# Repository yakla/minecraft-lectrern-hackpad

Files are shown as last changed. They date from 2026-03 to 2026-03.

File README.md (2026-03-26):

# Minecraft Lectern Hackpad
A custom 6-key mechanical macro pad inspired by the Minecraft Lectern, designed for the **Hack Club Blueprint**.

## The Vision
the idea was i fast hackpad project with cool visuals. so i made it with a minecraft lectern block.
## Technical Specs
* **Controller:** Seeed Studio XIAO RP2040
* **Keys:** 6 Mechanical Switches (3x2 Matrix)
* **Visuals:** 128x32 OLED Display + WS2812B RGB LEDs
* **Firmware:** KMK / CircuitPython

# Hardware
* **XIAO RP2040** – The microController
* **6 x Mechanical Switches** - hackpad keys
* **1 x 0.91" White OLED** – Crisp 128x32 display for real-time status and custom graphics.
* **4 x WS2812B RGB LEDs** – Integrated lighting for that essential setup flex.
* **Custom 2-Layer PCB** – Engineered in KiCad 
* **6 x 1N4148W Diodes**

## Design Process
- **CAD:** Designed in **Onshape**. https://cad.onshape.com/documents/4aa1c7f92bdb34f3150a863a/w/03df906dbdf565c718d04fe4/e/68b5d359d9c8e5f142904c5d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
- **PCB:** Custom 2-layer board designed in **KiCad** with SMD diode protection.            |

## cad


## pcb design



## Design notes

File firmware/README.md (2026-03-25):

# KMK Firmware Setup

This repo already includes a local copy of KMK in [`../kmk_firmware`](../kmk_firmware).

## Board mapping

These pins were taken from the KiCad PCB for the XIAO RP2040:

- Matrix columns: `D0`, `D1`, `D9`
- Matrix rows: `D2`, `D3`
- OLED: `D4` = SDA, `D5` = SCL
- WS2812 chain: `D10`

## What to copy to `CIRCUITPY`

1. Install CircuitPython for the Seeed Studio XIAO RP2040.
2. Copy `kmk_firmware/kmk/` to the root of `CIRCUITPY`.
3. Copy `kmk_firmware/boot.py` to the root of `CIRCUITPY`.
4. Copy [`main.py`](./main.py) and [`kb.py`](./kb.py) to the root of
   `CIRCUITPY`.
5. Copy these CircuitPython display libraries into `CIRCUITPY/lib/`:

   - `adafruit_displayio_ssd1306.mpy`
   - `adafruit_display_text/`
6. Copy this CircuitPython RGB library into `CIRCUITPY/lib/`:

   - `neopixel.py`

[`main.py`](./main.py) keeps the keymap minimal, but it does initialize the
OLED on `D4`/`D5` and the WS2812 LEDs on `D10`. The OLED defaults to an idle
screen and switches to the pressed key name for one second whenever a key is
pressed.

## Example Linux copy command

```sh
cp -r kmk_firmware/kmk /run/media/$USER/CIRCUITPY/
cp kmk_firmware/boot.py firmware/main.py firmware/kb.py /run/media/$USER/CIRCUITPY/
```

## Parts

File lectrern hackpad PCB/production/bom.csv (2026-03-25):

Designator | Footprint | Quantity | Value | LCSC Part #
D1, D2, D3, D4, D5, D6 | 1206 | 6 | D
D10, D7, D8, D9 | LED_WS2812B_PLCC4_5.0x5.0mm_P3.2mm | 4 | WS2812B
J1 | PinHeader_1x04_P2.54mm_Vertical | 1 | oled connectors
SW1, SW2, SW3, SW4, SW5, SW6 | MX-Solderable-1U | 6 | SW_Push
U1 | XIAO-Generic-Hybrid-14P-2.54-21X17.8MM | 1 | MOUDLE-SEEEDUINO-XIAO

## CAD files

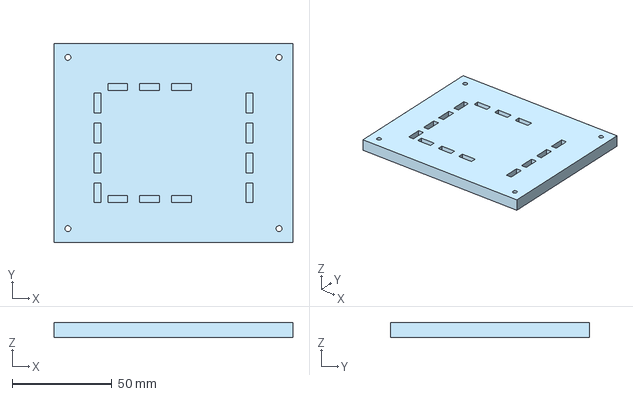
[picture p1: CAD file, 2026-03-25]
cad/lectrern hackpad.step
120.0 x 100.0 x 7.40 mm

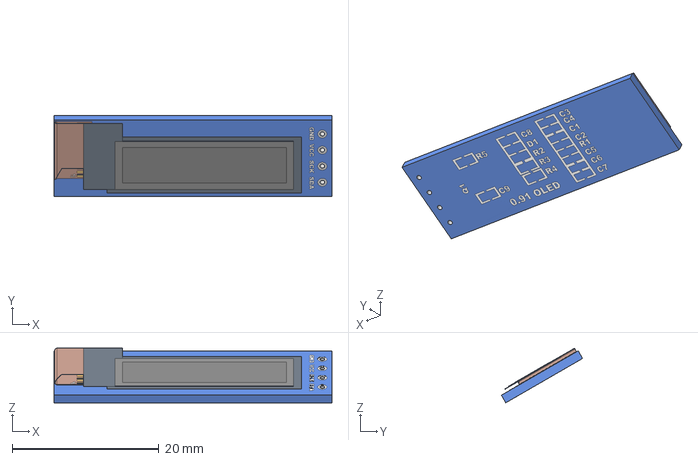
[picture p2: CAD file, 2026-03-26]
cad/parts/fast model - 0.91in oled Module - Board.step
37.9 x 11.1 x 7.45 mm

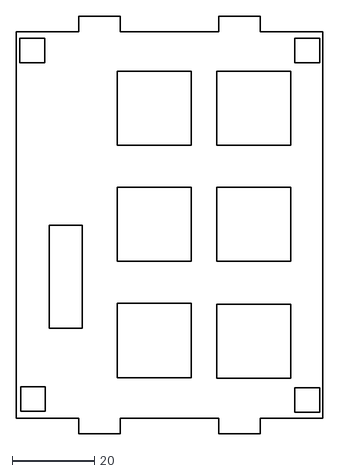
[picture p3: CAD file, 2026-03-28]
laser dxf files/fast model - top enclosure.dxf
74.4 x 101.4

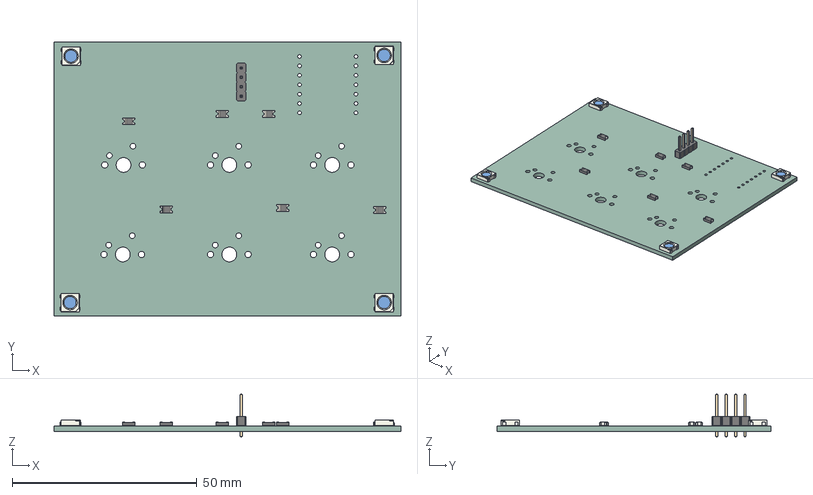
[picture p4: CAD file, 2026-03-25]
lectrern hackpad PCB/lectrern hackpad.step
93.8 x 74.0 x 11.5 mm
D_1206_3216Metric x 6
LED_WS2812B_PLCC4_5.0x5.0mm_P3.2mm x 4
PinHeader_1x04_P2.54mm_Vertical
lectrern hackpad_PCB

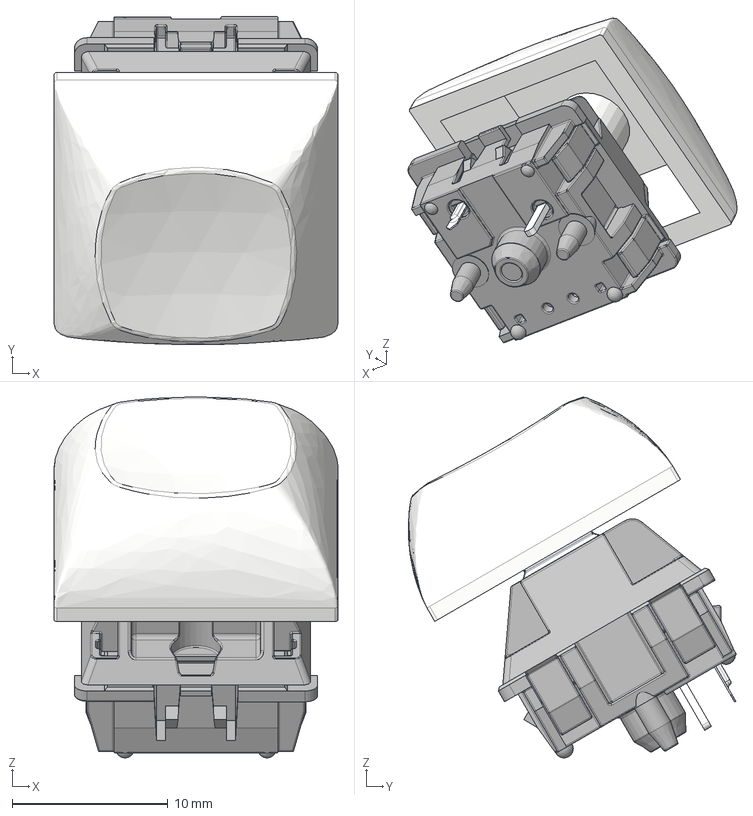
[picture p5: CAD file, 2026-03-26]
cad/parts/key.step
18.2 x 21.0 x 23.1 mm
MX �� ������_��_ __��1
���___Ĭ��__��_ x 2
MX�� ���� �ײ� �̡�2 __Ĭ��_��2____��_
MX �� ���娢��_���顧_ _
DSA 1u v2

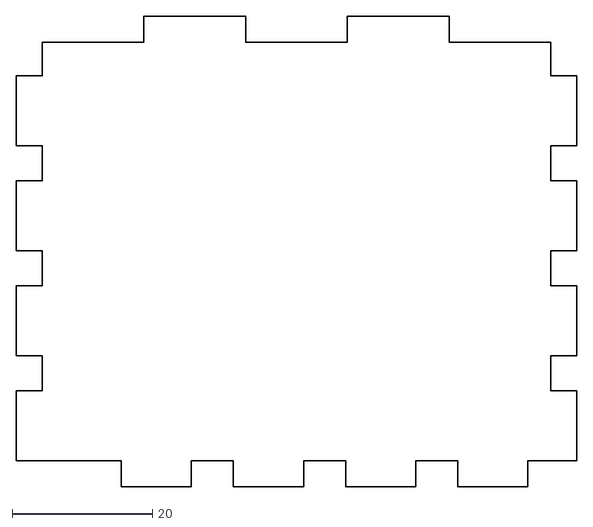
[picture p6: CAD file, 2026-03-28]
laser dxf files/fast model - back pannel.dxf
80.0 x 67.1

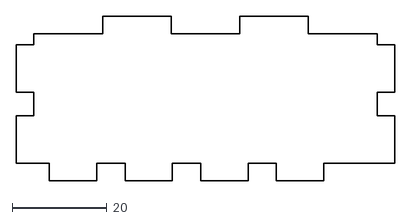
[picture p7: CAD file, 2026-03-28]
laser dxf files/fast model - front pannel.dxf
80.0 x 34.7

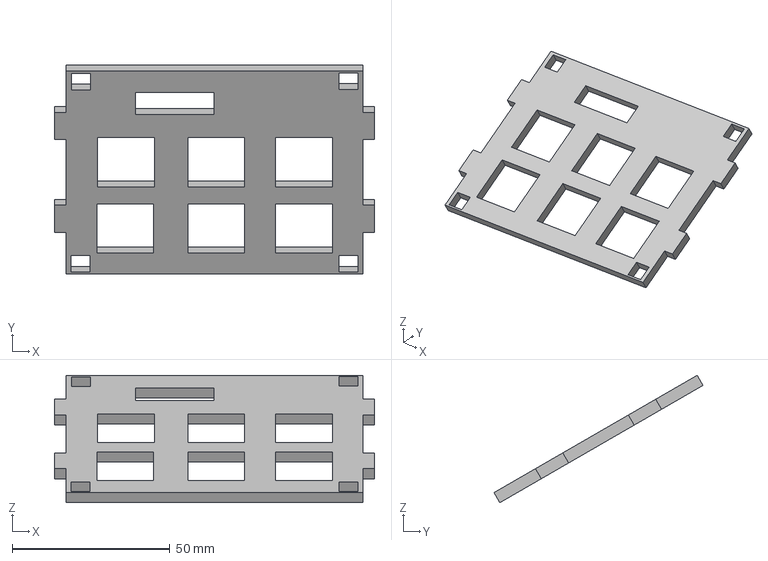
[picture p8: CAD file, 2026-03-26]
cad/parts/fast model - top enclosure.step
101.4 x 66.3 x 40.4 mm

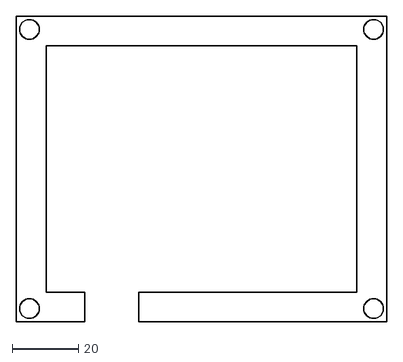
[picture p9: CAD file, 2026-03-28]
laser dxf files/fast model - top plate mid.dxf
112.0 x 92.4

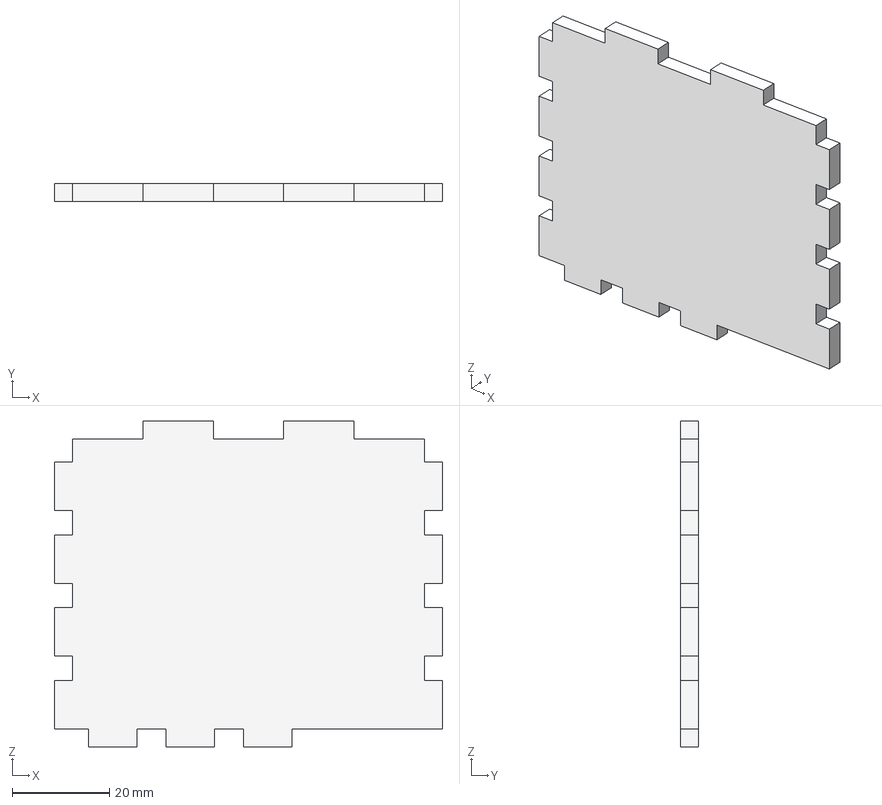
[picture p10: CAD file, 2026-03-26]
cad/parts/fast model - back pannel.step
80.0 x 3.70 x 67.1 mm

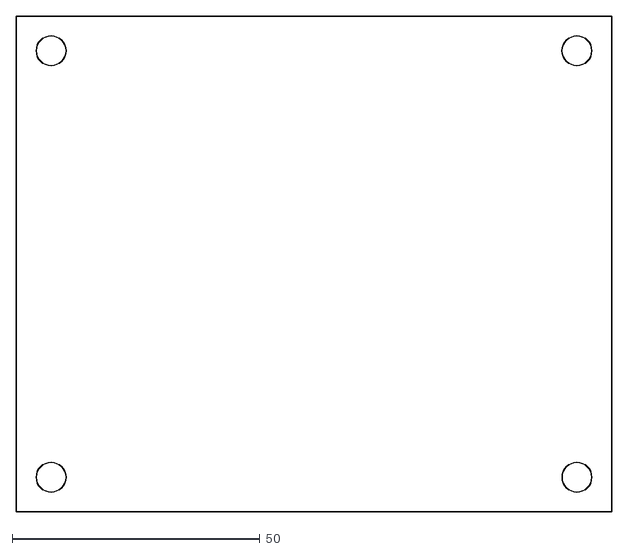
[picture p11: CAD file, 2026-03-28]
laser dxf files/fast model - base bottom.dxf
120.0 x 100.0

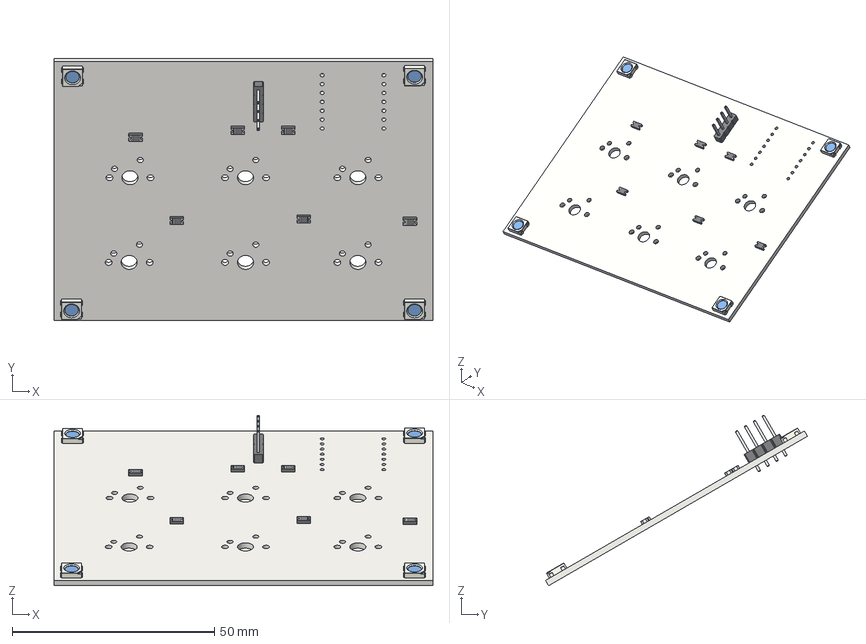
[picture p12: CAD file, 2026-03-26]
cad/parts/fast model - PCB.step
93.8 x 64.8 x 42.2 mm

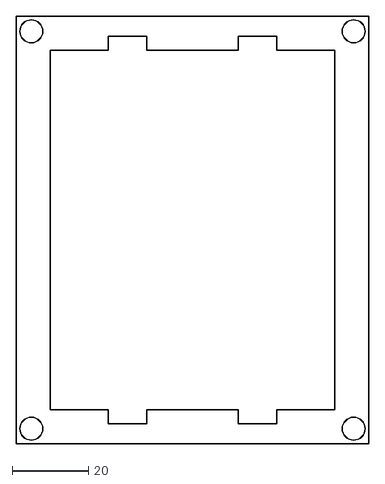
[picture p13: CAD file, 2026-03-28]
laser dxf files/fast model - top plate top.dxf
92.4 x 112.0

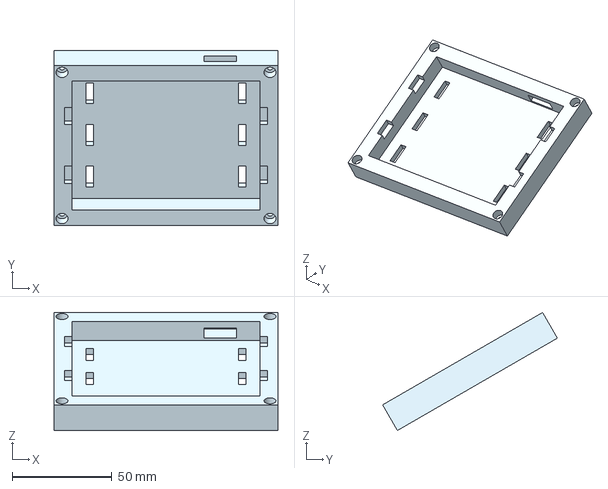
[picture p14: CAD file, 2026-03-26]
cad/parts/fast model - top plate.step
112.0 x 87.4 x 59.0 mm

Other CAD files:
cad/parts/fast model - base.step
laser dxf files/fast model - top plate bottom.dxf
cad/parts/fast model - left side pannel.step
laser dxf files/fast model - base top.dxf
cad/parts/fast model - front pannel.step
cad/parts/fast model - right side pannel.step

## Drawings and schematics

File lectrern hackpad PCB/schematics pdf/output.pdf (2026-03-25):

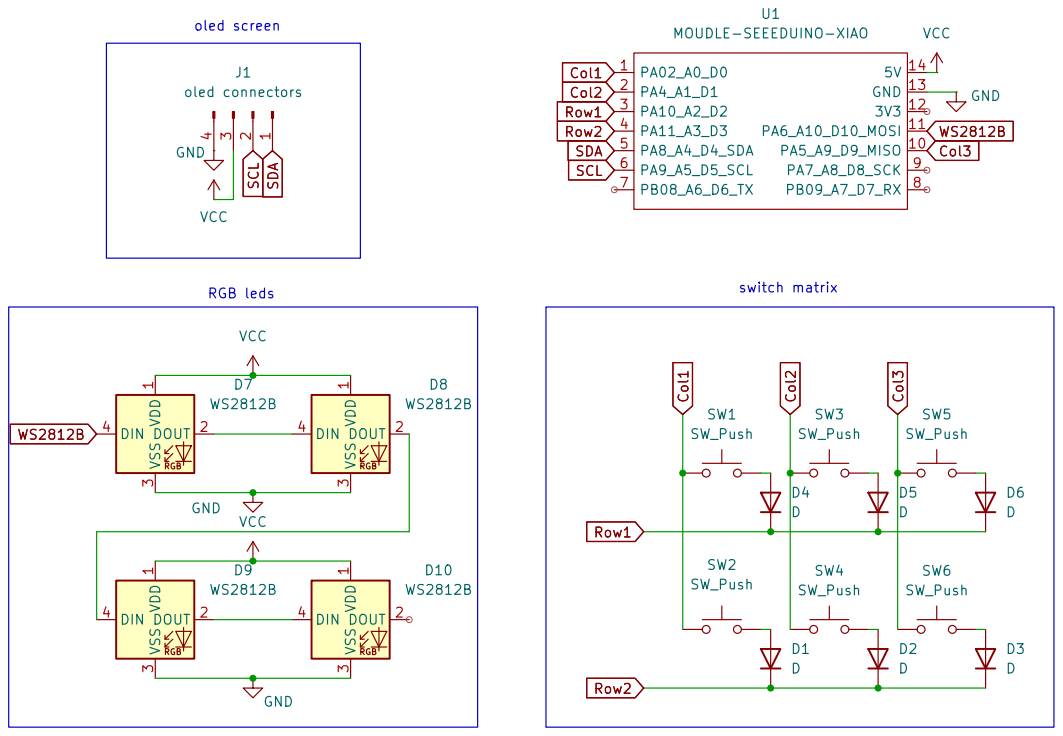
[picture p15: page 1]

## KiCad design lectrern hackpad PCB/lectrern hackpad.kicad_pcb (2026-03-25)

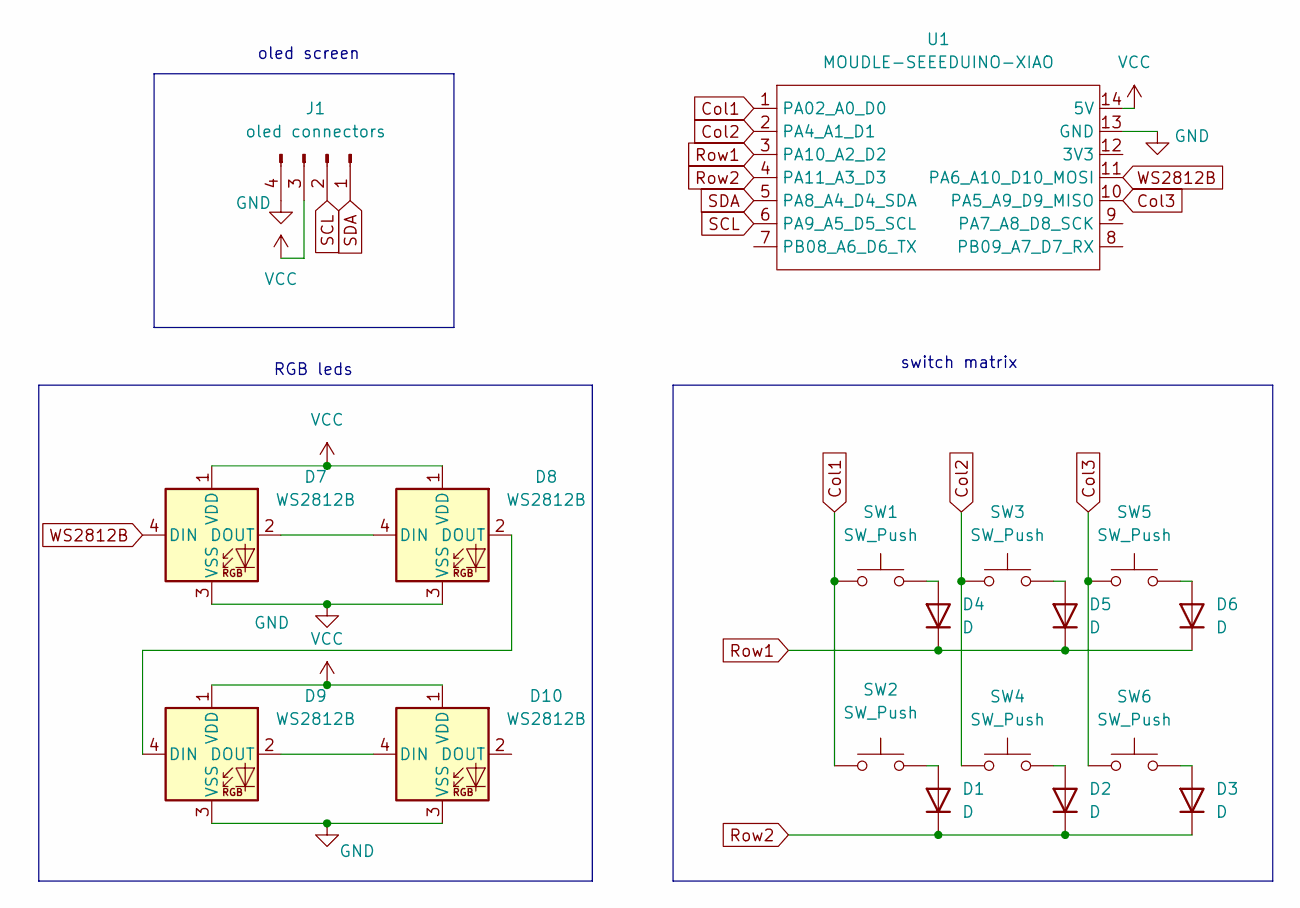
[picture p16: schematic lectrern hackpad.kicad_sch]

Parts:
D1, D2, D3, D4, D5, D6: D; D_1206_3216Metric_Pad1.42x1.75mm_HandSolder
D7, D8, D9, D10: WS2812B; LED_WS2812B_PLCC4_5.0x5.0mm_P3.2mm
J1: oled connectors; PinHeader_1x04_P2.54mm_Vertical
SW1, SW2, SW3, SW4, SW5, SW6: SW_Push; MX-Solderable-1U
U1: MOUDLE-SEEEDUINO-XIAO; XIAO-Generic-Hybrid-14P-2.54-21X17.8MM

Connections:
Col1: SW1.1, SW2.1, U1.1 (PA02_A0_D0)
Col2: SW3.1, SW4.1, U1.2 (PA4_A1_D1)
Col3: SW5.1, SW6.1, U1.10 (PA5_A9_D9_MISO)
GND: D7.3 (VSS), D8.3 (VSS), D9.3 (VSS), D10.3 (VSS), J1.4, U1.13 (GND)
unnamed: D1.2 (A), SW2.2
unnamed: D2.2 (A), SW4.2
unnamed: D3.2 (A), SW6.2
unnamed: D4.2 (A), SW1.2
unnamed: D5.2 (A), SW3.2
unnamed: D6.2 (A), SW5.2
unnamed: D7.2 (DOUT), D8.4 (DIN)
unnamed: D8.2 (DOUT), D9.4 (DIN)
unnamed: D9.2 (DOUT), D10.4 (DIN)
Row1: D4.1 (K), D5.1 (K), D6.1 (K), U1.3 (PA10_A2_D2)
Row2: D1.1 (K), D2.1 (K), D3.1 (K), U1.4 (PA11_A3_D3)
SCL: J1.2, U1.6 (PA9_A5_D5_SCL)
SDA: J1.1, U1.5 (PA8_A4_D4_SDA)
VCC: D7.1 (VDD), D8.1 (VDD), D9.1 (VDD), D10.1 (VDD), J1.3, U1.14 (5V)
WS2812B: D7.4 (DIN), U1.11 (PA6_A10_D10_MOSI)

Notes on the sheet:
RGB leds
switch matrix
oled screen

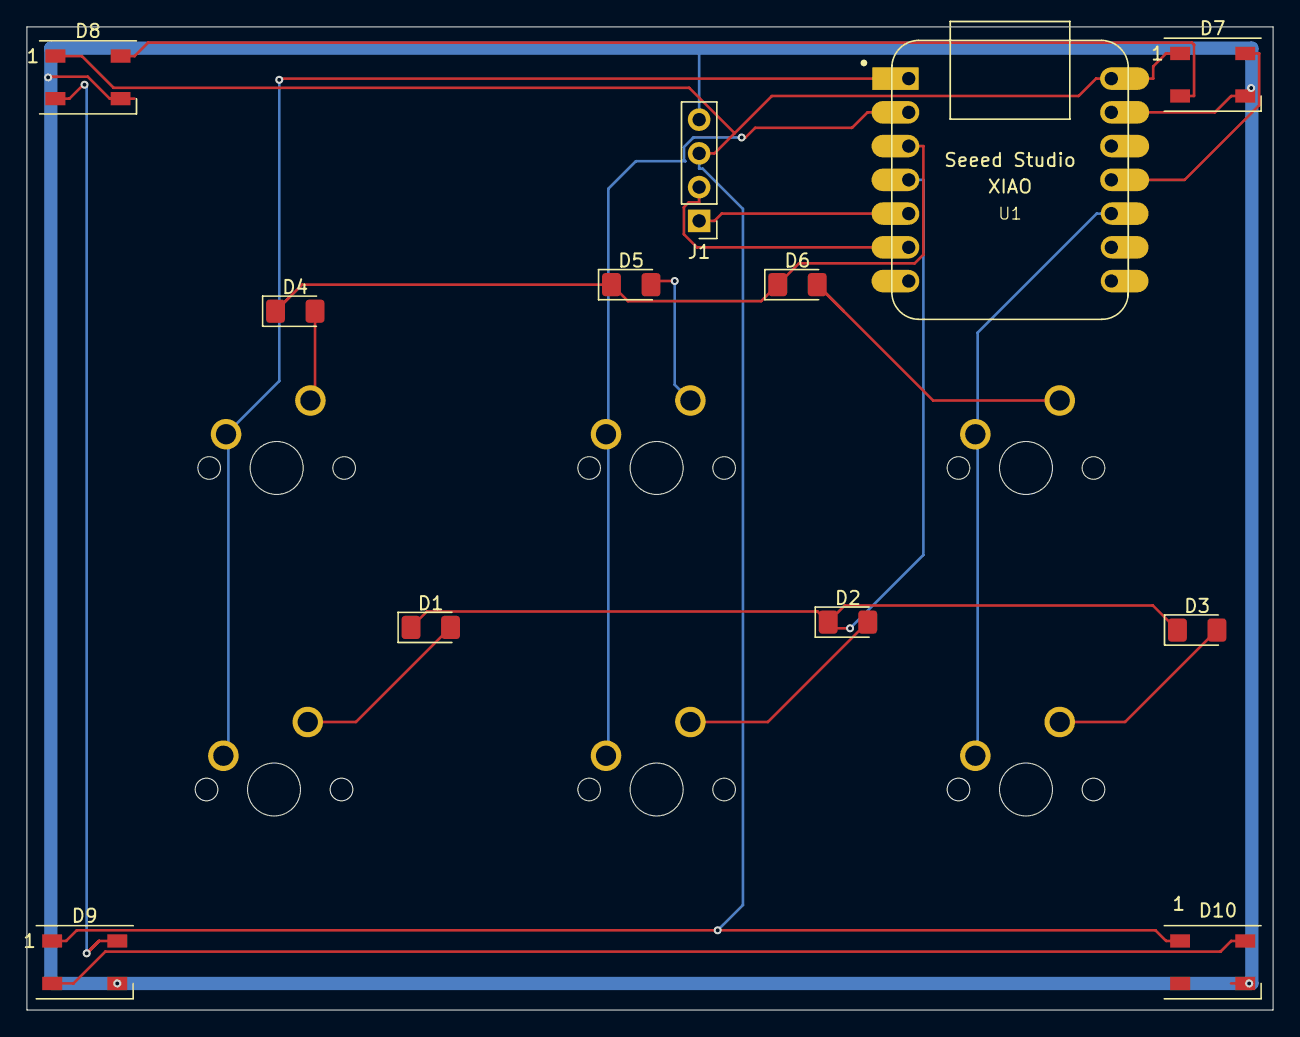
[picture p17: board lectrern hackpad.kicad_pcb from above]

Board: 2 copper layers, 93.8 x 74.0 mm, 18 parts (0 on the bottom side), 19 nets.

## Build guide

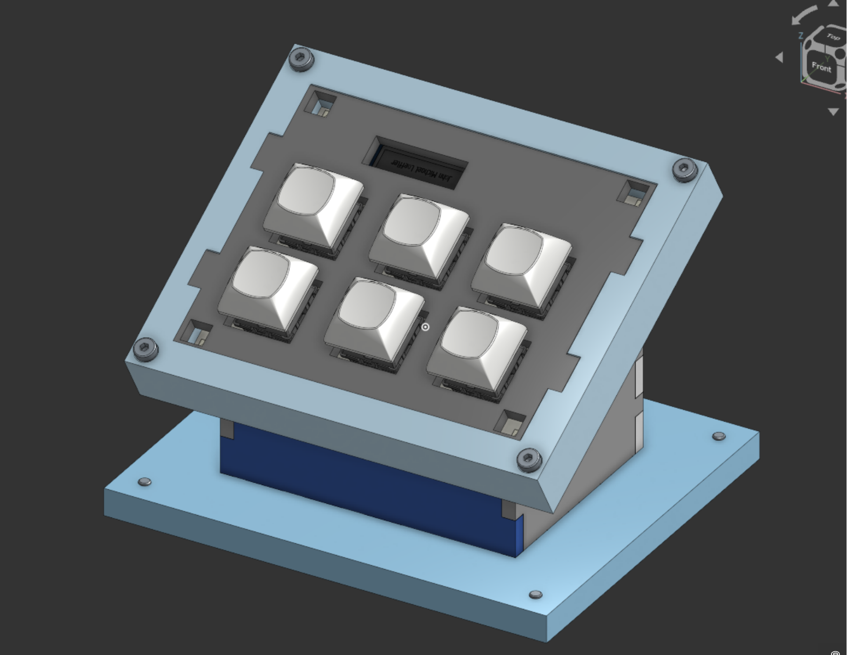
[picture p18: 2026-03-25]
Screenshot 2026-03-25 at 20-05-16 lectrern hackpad Assembly 1.png

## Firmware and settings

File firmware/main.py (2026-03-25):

from sys import path

import board

from kb import KMKKeyboard
from kmk.extensions.display import Display, TextEntry, ImageEntry
from kmk.extensions.display.ssd1306 import SSD1306
from kmk.extensions.rgb import RGB
from kmk.keys import KC
from kmk.modules import Module

keyboard = KMKKeyboard()

rgb = RGB(
    pixel_pin=board.D10,
    num_pixels=4,
    val_default=40,
)
keyboard.extensions.append(rgb)

display = Display(
    display=SSD1306(sda=board.D4, scl=board.D5),
    entries=[

        TextEntry(text='Minecraft', x=64, y=4, x_anchor='M', y_anchor='T'),
        TextEntry(text='Lectern', x=64, y=18, x_anchor='M', y_anchor='T'),
    ],
    flip=True,
)
keyboard.extensions.append(display)

KEY_LABELS = {
    0: 'F13',
    1: 'F14',
    2: 'F15',
    3: 'F16',
    4: 'F17',
    5: 'F18',
}


def show_idle():
    display.entries = [
        ImageEntry(image = "key_up.bmp", x=32, y=16),
        TextEntry(text='Minecraft', x=96, y=16, x_anchor='M', y_anchor='T'),
    ]
    display.render(keyboard.active_layers[0])


def show_pressed(name):
    display.entries = [
        ImageEntry(image = "key_down.bmp", x=32, y=16),
        TextEntry(text=name, x=100, y=16, x_anchor='M', y_anchor='T'),
    ]
    display.render(keyboard.active_layers[0])


class DisplayListener(Module):
    def __init__(self):
        self._timeout = None

    def during_bootup(self, keyboard):
        return

    def before_matrix_scan(self, keyboard):
        return

    def after_matrix_scan(self, keyboard):
        return

    def process_key(self, keyboard, key, is_pressed, int_coord):
        if is_pressed and int_coord is not None:
            show_pressed(KEY_LABELS.get(int_coord, f'Key {int_coord + 1}'))

            if self._timeout is not None:
                keyboard.cancel_timeout(self._timeout)

            self._timeout = keyboard.set_timeout(1000, show_idle)

        return key

    def before_hid_send(self, keyboard):
        return

    def after_hid_send(self, keyboard):
        return

    def on_powersave_enable(self, keyboard):
        return

    def on_powersave_disable(self, keyboard):
        return


keyboard.modules.append(DisplayListener())

keyboard.keymap = [
    [
        KC.F13,
        KC.F14,
        KC.F15,
        KC.F16,
        KC.F17,
        KC.F18,
    ]
]

if __name__ == '__main__':
    keyboard.go()

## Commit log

2026-03-25 Initial commit: PCB design and Onshape model
    [Bom table.csv, Bom table.ods, bom.csv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]
2026-03-25 Add Bill of Materials section to README
2026-03-25 finish all the code firmware
    [Bom table.csv, lectrern hackpad.kicad_pcb, lectrern hackpad.kicad_sch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]
2026-03-26 Update README with hardware details and BOM removal
    Added hardware specifications and removed BOM section.
2026-03-26 Add STEP file for panel design
    [Bom table.csv, Bom table.ods, fast model - PCB.step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]
2026-03-26 Update cad
    [fast model - 0.91in oled Module - Board.step, key.step]
2026-03-28 add the dxf laser files from the cad. still haven't added the minecraft texture to it
    [fast model - back pannel.dxf, fast model - base bottom.dxf, fast model - base top.dxf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]
